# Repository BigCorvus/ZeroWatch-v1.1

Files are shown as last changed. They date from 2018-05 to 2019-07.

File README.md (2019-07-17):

# ZeroWatch-v1.1


**Replacement board for a cheap chinese U8/U80 watch.**  
Based on the work of Dan Geiger.
Features:<br />
- ATSAMD21 microcontroller with Arduino support via USB bootloader<br />
- capacitive touchscreen (based on the BL6280 controller)<br />
- HM11 bluetooth 4.0 module with amputated PCB antenna and primitive coax dipole instead<br />
- ST7735 128x128 18-pin SPI tft (the one that's inside the watch already)<br />
- MPU9250 9-DOF IMU<br />
- BME680 environmental sensor<br />
- vibration motor. I decided to go with https://de.aliexpress.com/item/Free-shipping-100pcs-lot-4-10-MM-Ultra-Micro-Vibration-Motor-Rotor-motor-DC-Massager-motor/32748925343.html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 as the vibration motor to save space for a bigger battery.<br />
- infrared transmitter (APA3010F3C-GX LED)<br />
- piezo disc (optional)<br />
- I equipped mine with a QI inductive charging pad<br />

The software is based on Dan Geigers ingenious menu structure which enables you to add new apps easily.
It's quite raw and buggy but demonstrates most features and is optimized for power consumption. With the 403030 lipo I can get 8 days of standby time with bluetooth constantly advertising and the ATSAMD21's inbuilt RTC running.<br />

**Some tips if you want to repeat the project:**  
- The cheapest versions of the U8 (there are even ones below 10$, a great contribution to a healthy environment!) are usually so stripped-down that they are not useful anymore! They have their capacitive touch controller on the main PCB an not on a flex-rigid assembly. I found the U80 by NAIKU to be a good hacking victim. Search this on Aliexpress. Its design is slightly different to the U8 from the outside but from the inside everything fits. Note: the U8 by the same brand is useless.  
  
The pic shows some useless variants on the right and some hackable ones on the left (with their 6pin FPC connectors desoldered for the most part). As you can see,on the useless variants there's no touch controller on the ribbon cable but a 15pin FPC connector with nothing but the traces to the glass. Also, v1.0 and v1.2's bare PCB are depicted on the very left ;)  

- Finding a proper screen might be a problem. 18 pin versions of the 1.44'' ST7735/ILI9163 screen with the right dimensions are rare. In fact I've only found one source: https://de.aliexpress.com/item/Maithoga-1-44-zoll-18-PIN-SPI-TFT-LCD-St7735-Stick-IC-128RGB-128/32843155779.html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. Some screens found in the cheap U8/U80 watches have weird controller settings and dispay inverted colors or don't show the small fonts so be aware. You might need to buy several differen variants. Note: only 14 of the 18 pins have to be soldered to the PCB.  
- some modifications on the enclosure are needed. In order to accommodate the v1.1 board you have to cut away the plastic brackets that surround the microphone. This is best done usind electronics side cutters. Some other plastic tabs might need to be removed depending on the variant you have. But the enclosures are surprisingly similar with few variations between versions.  
- The button can be installed either using the native one or by installing a SW1256CT-ND switch (digikey). The latter requires some hacking to the enclosure  
- a small hole has to be drilled for the IR LED if you wish to use one.
- the HM-11 should be flashed with the newest firmware before installing on the v1.1 PCB.   
- if you have a PCB manufactured, the substrate thickness should be between 0.4 and 0.8mm, so OSH Park's 0.8mm service is a good choice.
- in the latest modification I replaced the HM11 with a tiny nRF52832 module (https://de.aliexpress.com/item/32840369737.html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) which I  flashed with a modified BLE UART example inside the Adafruit nRF52 core. It can be brought into sub-µA deep sleep by the ATSAMD. By using a passthrough sketch for the ATSAMD which lets it act as an USB-to UART bridge you can even program the nRF52832 via USB and the Arduino IDE. I tested the concept and it seems to be the best solution so far. Code and wiring scheme for this will be puplished as soon as I have time for it.

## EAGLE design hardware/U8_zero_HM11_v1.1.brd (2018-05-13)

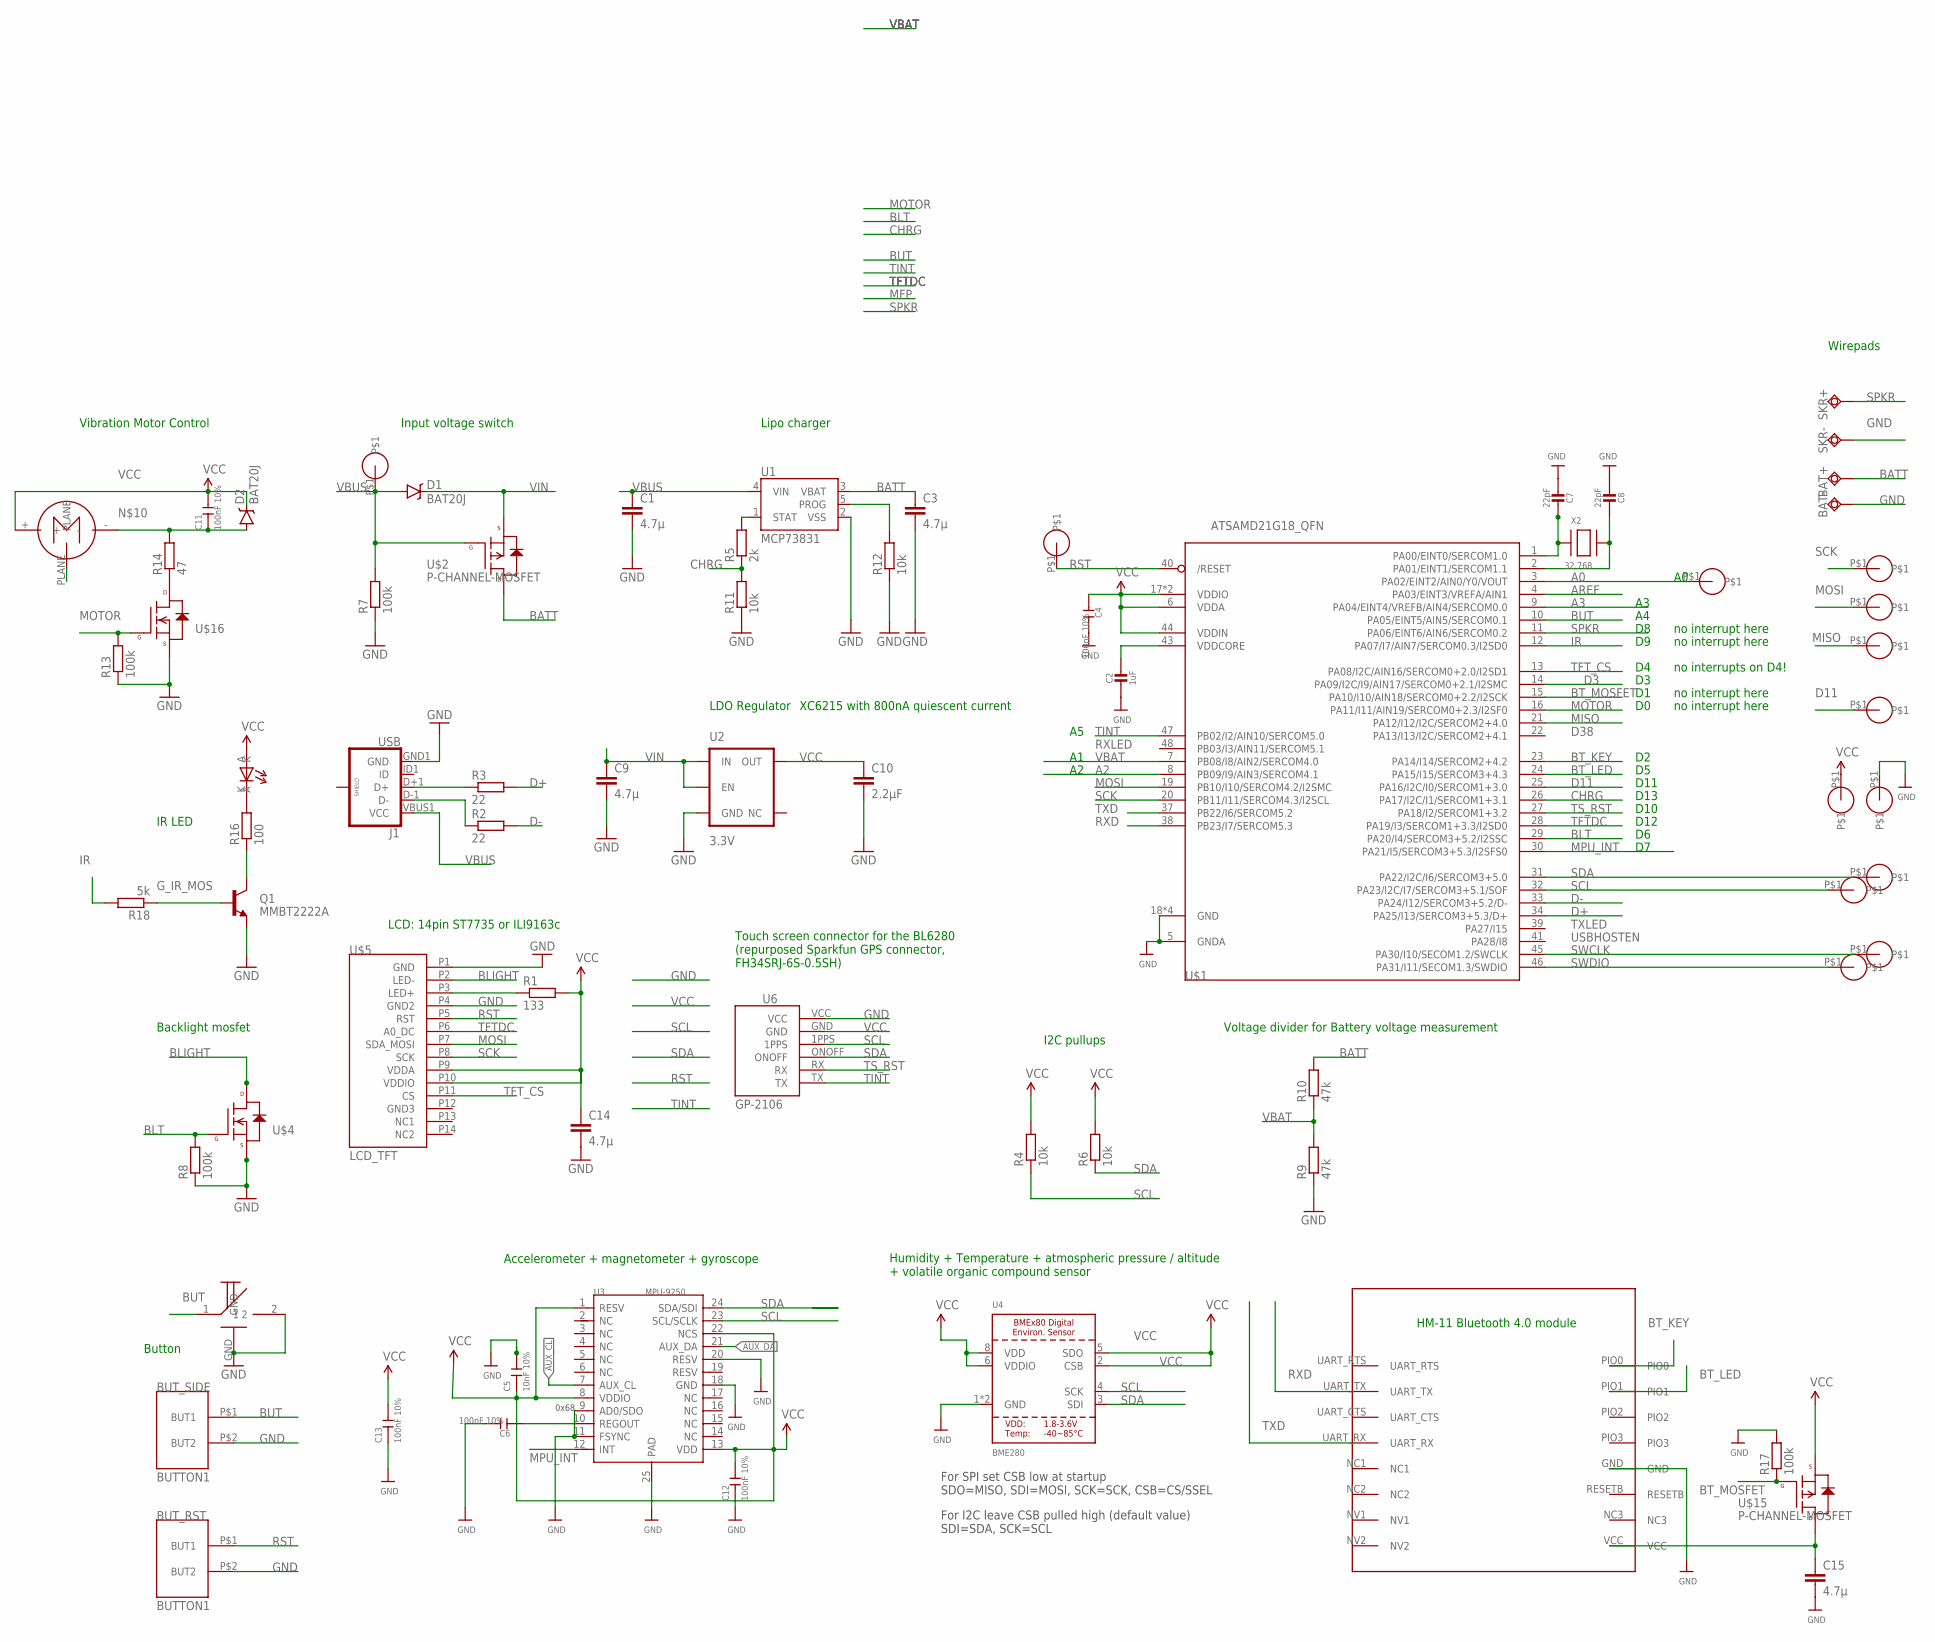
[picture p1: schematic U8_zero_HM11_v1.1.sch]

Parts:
BAT+: TPSQTP16R; TP16R
BAT-: TPSQTP16R; TP16R
BUT_RST: BUTTON1
BUT_SIDE: BUTTON1
C1, C3, C9, C14, C15: 4.7µ; C0603
C2: 1uF; 0603-NO
C4, C6, C11, C12, C13: 100nF 10%; C0603
C5: 10nF 10%; C0603
C7, C8: 22pF; 0603-NO
C10: 2.2µF; C0603
CLK: MINIPAD
D1, D2: BAT20J; SOD-323
DIO, DIO1, DIO2, DIO3, DIO4, DIO5: MINIPAD
J1: USB; USB-B-MICRO-SMD_V03
Q1: MMBT2222A; SOT23-3
R1: 133; R0603
R2, R3: 22; R0603
R4, R6, R11, R12: 10k; R0603
R5: 2k; R0603
R7, R8, R13, R17: 100k; R0603
R9, R10: 47k; R0603
R14: 47; R0603
R16: 100; R0603
R18: 5k; R0603
SKR+: TPSQTP12R; TP12R
SKR-: TPSQTP12R; TP12R
U1: MCP73831; SOT23-5
U2: 3.3V; SOT23-5
U3: MPU-9250; LEAD-QFN24
U4: BME280
U6: GP-2106
U$1: ATSAMD21G18_QFN; TQFN48_7MM
U$2, U$15: P-CHANNEL-MOSFET; SOT23-3
U$3, U$18, U$20, U$21, U$41, U$42: MINIPAD
U$4, U$16: N-CHANNEL-MOSFET-BSS138; SOT23-3
U$5: LCD_TFT; LCD_FPC14
U$8: HM-11
U$22: B3U-3100P-B
U$23: VIBRO
U$24: APA3010F3C-GX
X2: 32.768; XTAL3215

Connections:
A0: U$1.3 (PA02/EINT2/AIN0/Y0/VOUT), U$20.P$1
A2: U$1.8 (PB09/I9/AIN3/SERCOM4.1)
A3: U$1.9 (PA04/EINT4/VREFB/AIN4/SERCOM0.0)
AREF: U$1.4 (PA03/EINT3/VREFA/AIN1)
AUX_CL: U3.7 (AUX_CL)
AUX_DA: U3.21 (AUX_DA)
BATT: BAT+.TP, C3.1, R10.2, U1.3 (VBAT), U$2.3 (D)
BLIGHT: U$4.3 (D), U$5.P2 (LED-)
BLT: R8.2, U$1.29 (PA20/I4/SERCOM3+5.2/I2SSC), U$4.1 (G)
BT_KEY: U$1.23 (PA14/I14/SERCOM2+4.2), U$8.PIO0
BT_LED: U$1.24 (PA15/I15/SERCOM3+4.3), U$8.PIO1
BT_MOSFET: R17.1, U$1.15 (PA10/I10/AIN18/SERCOM0+2.2/I2SCK), U$15.1 (G)
BUT: BUT_SIDE.P$1 (BUT1), U$1.10 (PA05/EINT5/AIN5/SERCOM0.1), U$22.1
CHRG: R5.1, R11.2, U$1.26 (PA17/I2C/I1/SERCOM1+3.1)
D3: U$1.14 (PA09/I2C/I9/AIN17/SERCOM0+2.1/I2SMC)
D11: DIO4.P$1, U$1.25 (PA16/I2C/I0/SERCOM1+3.0)
D+: R3.2, U$1.34 (PA25/I13/SERCOM3+5.3/D+)
D-: R2.2, U$1.33 (PA24/I12/SERCOM3+5.2/D-)
GND: BAT-.TP, BUT_RST.P$2 (BUT2), BUT_SIDE.P$2 (BUT2), C1.2, C2.2, C3.2, C4.2, C5.2, C6.2, C7.2, C8.2, C9.2, C10.2, C12.1, C13.1, C14.2, C15.2, J1.GND1 (GND), Q1.2 (E), R7.1, R8.1, R9.1, R11.1, R12.1, R13.1, R17.2, SKR-.TP, U1.2 (VSS), U2.2 (GND), U3.9 (AD0/SDO), U3.11 (FSYNC), U3.18 (GND), U3.20 (RESV), U3.25 (PAD), U4.1 (GND), U4.7 (GND), U6.VCC, U$1.5 (GNDA), U$1.18 (GND), U$1.35 (GND), U$1.42 (GND), U$1.THERMAL (GND), U$4.2 (S), U$5.P1 (GND), U$5.P4 (GND2), U$8.GND, U$16.2 (S), U$22.2, U$22.GND, U$42.P$1
G_IR_MOS: Q1.1 (B), R18.1
IR: R18.2, U$1.12 (PA07/I7/AIN7/SERCOM0.3/I2SD0)
MISO: DIO1.P$1, U$1.21 (PA12/I12/I2C/SERCOM2+4.0)
MOSI: DIO2.P$1, U$1.19 (PB10/I10/SERCOM4.2/I2SMC), U$5.P7 (SDA_MOSI)
MOTOR: R13.2, U$1.16 (PA11/I11/AIN19/SERCOM0+2.3/I2SF0), U$16.1 (G)
MPU_INT: U3.12 (INT), U$1.30 (PA21/I5/SERCOM3+5.3/I2SFS0)
unnamed: C6.1, U3.10 (REGOUT)
unnamed: C7.1, U$1.1 (PA00/EINT0/SERCOM1.0), X2.P$1
unnamed: C8.1, U$1.2 (PA01/EINT1/SERCOM1.1), X2.P$2
unnamed: R14.1, U$16.3 (D)
unnamed: J1.D+1 (D+), R3.1
unnamed: J1.D-1 (D-), R2.1
unnamed: R12.2, U1.5 (PROG)
unnamed: R5.2, U1.1 (STAT)
unnamed: R1.1, U$5.P3 (LED+)
unnamed: C11.1, D2.A, R14.2, U$23.-
unnamed: Q1.3 (C), R16.1
unnamed: R16.2, U$24.K
unnamed: C15.1, U$8.VCC, U$15.3 (D)
PLANE: U$23.PLANE
RST: BUT_RST.P$1 (BUT1), U$1.40 (/RESET), U$3.P$1, U$5.P5 (RST)
RXD: U$1.38 (PB23/I7/SERCOM5.3), U$8.UART_TX
SCK: DIO3.P$1, U$1.20 (PB11/I11/SERCOM4.3/I2SCL), U$5.P8 (SCK)
SCL: R4.1, U3.23 (SCL/SCLK), U4.4 (SCK), U6.1PPS, U$1.32 (PA23/I2C/I7/SERCOM3+5.1/SOF), U$21.P$1
SDA: R6.1, U3.24 (SDA/SDI), U4.3 (SDI), U6.ONOFF, U$1.31 (PA22/I2C/I6/SERCOM3+5.0), U$18.P$1
SPKR: SKR+.TP, U$1.11 (PA06/EINT6/AIN6/SERCOM0.2)
SWCLK: CLK.P$1, U$1.45 (PA30/I10/SECOM1.2/SWCLK)
SWDIO: DIO.P$1, U$1.46 (PA31/I11/SECOM1.3/SWDIO)
TFTDC: U$1.28 (PA19/I3/SERCOM1+3.3/I2SD0), U$5.P6 (A0_DC)
TFT_CS: U$1.13 (PA08/I2C/AIN16/SERCOM0+2.0/I2SD1), U$5.P11 (CS)
TINT: U6.TX, U$1.47 (PB02/I2/AIN10/SERCOM5.0)
TS_RST: U6.RX, U$1.27 (PA18/I2/SERCOM1+3.2)
TXD: U$1.37 (PB22/I6/SERCOM5.2), U$8.UART_RX
VBAT: R9.2, R10.1, U$1.7 (PB08/I8/AIN2/SERCOM4.0)
VBUS: C1.1, D1.A, DIO5.P$1, J1.VBUS1 (VCC), R7.2, U1.4 (VIN), U$2.1 (G)
VCC: C4.1, C5.1, C10.1, C11.2, C12.2, C13.2, C14.1, D2.C, R1.2, R4.2, R6.2, U2.5 (OUT), U3.1 (RESV), U3.8 (VDDIO), U3.13 (VDD), U3.22 (NCS), U4.2 (CSB), U4.5 (SDO), U4.6 (VDDIO), U4.8 (VDD), U6.GND, U$1.6 (VDDA), U$1.17 (VDDIO), U$1.36 (VDDIO), U$1.44 (VDDIN), U$5.P9 (VDDA), U$5.P10 (VDDIO), U$15.2 (S), U$23.+, U$24.A, U$41.P$1
VDDCORE1: C2.1, U$1.43 (VDDCORE)
VIN: C9.1, D1.C, U2.1 (IN), U2.3 (EN), U$2.2 (S)

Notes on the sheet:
D38
TXLED
USBHOSTEN
RXLED
TXD
RXD
0x68
D12
D10
For SPI set CSB low at startup SDO=MISO, SDI=MOSI, SCK=SCK, CSB=CS/SSEL
For I2C leave CSB pulled high (default value) SDI=SDA, SCK=SCL
D11
D13
no interrupts on D4!
HM-11 Bluetooth 4.0 module
no interrupt here
LCD: 14pin ST7735 or ILI9163c
Touch screen connector for the BL6280 (repurposed Sparkfun GPS connector, FH34SRJ-6S-0.5SH)
Vibration Motor Control
Input voltage switch
Lipo charger
LDO Regulator
IR LED
Voltage divider for Battery voltage measurement
I2C pullups
Backlight mosfet
Button
Accelerometer + magnetometer + gyroscope
Humidity + Temperature + atmospheric pressure / altitude + volatile organic compound sensor
Wirepads
XC6215 with 800nA quiescent current

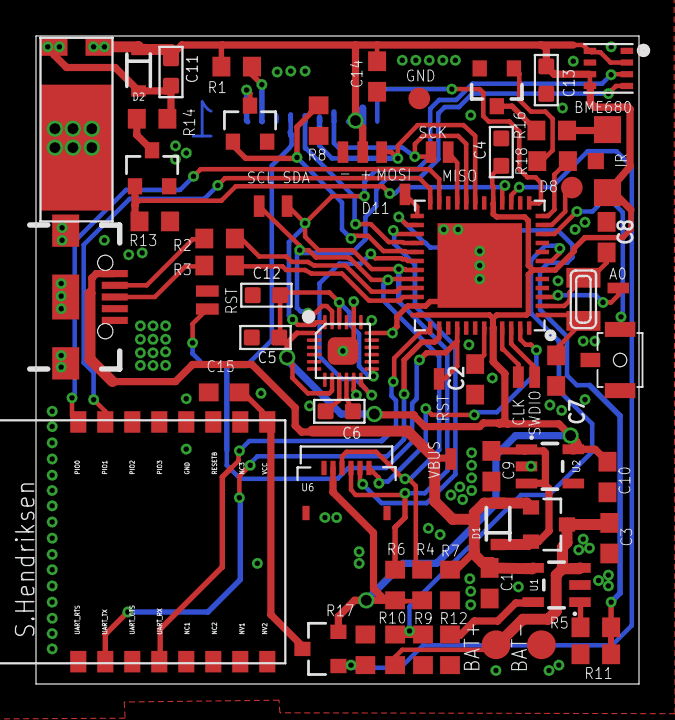
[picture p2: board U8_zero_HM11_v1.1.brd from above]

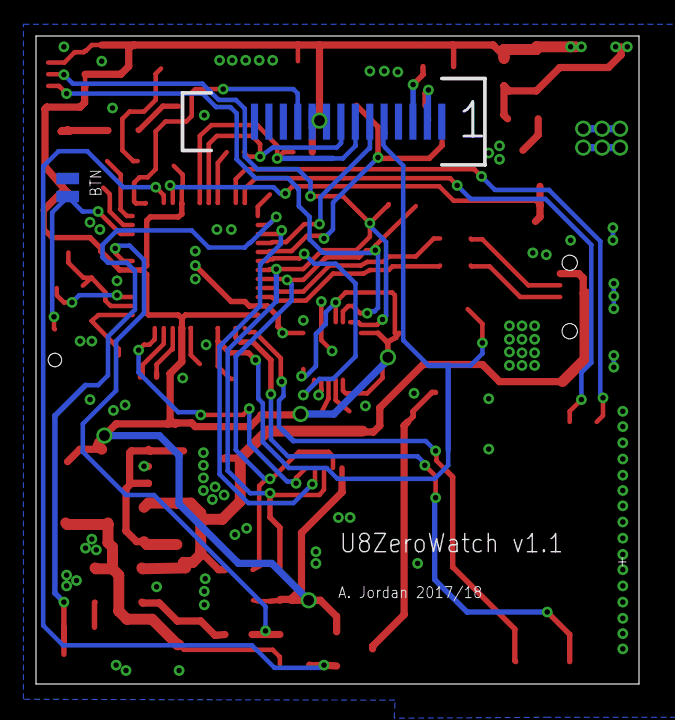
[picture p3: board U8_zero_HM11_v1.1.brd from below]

Board: 2 copper layers, 33.5 x 36.0 mm, 71 parts (2 on the bottom side), 50 nets.

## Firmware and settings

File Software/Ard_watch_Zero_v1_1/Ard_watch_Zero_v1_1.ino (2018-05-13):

#include "wiring_private.h" // pinPeripheral() function
#include <Wire.h>
#include <SPI.h>
#include <Adafruit_GFX.h>    // Core graphics library
#include <Adafruit_ST7735.h> // Hardware-specific library
#include <BL6280.h>
#include <SparkFunMPU9250-DMP.h>
#include <RTCZero.h>
#include <Adafruit_Sensor.h>
#include "Adafruit_BME680.h"
//#include "ClosedCube_BME680.h"
#include <IRLibSendBase.h>    // First include the send base
//Now include only the protocols you wish to actually use.
//The lowest numbered protocol should be first but remainder 
//can be any order.
#include <IRLib_P01_NEC.h>    
#include <IRLib_P02_Sony.h>   
#include <IRLibCombo.h>     // After all protocols, include this
// All of the above automatically creates a universal sending
// class called "IRsend" containing only the protocols you want.
// Now declare an instance of that sender.
#define SEALEVELPRESSURE_HPA (1013.25)


/* Create an rtc object */
RTCZero rtc;
/* Change these values to set the current initial time */
byte seconds = 0;
byte minutes = 00;
byte hours = 00;

/* Change these values to set the current initial date */
byte Day = 24;
byte Month = 5;
byte Year = 18;

// Color definitions
#define	BLACK   0x0000
#define	BLUE    0x001F
#define	RED     0xF800
#define	GREEN   0x07E0
#define CYAN    0x07FF
#define MAGENTA 0xF81F
#define YELLOW  0xFFE0
#define WHITE   0xFFFF

#define CS 4
#define DC 12
#define BACKLIGHT 6
#define CHARGE 13
#define BUTTON A4 //A4 is  7
#define TINT A5
#define SPKR 8
#define IR 9
#define AINT 7  //MPUinterrupt
#define VBAT A1
#define MOTOR PORT_PA11
#define TS_RST 10
#define BT_CTRL 2 //formerly SD_CS
#define BT_LED 5
#define BT_MOSFET 1


unsigned long stepCount = 0;
unsigned long stepTime = 0;
unsigned long lastStepCount = 0;

//create a new SPI for SD card
//SPIClass SD_SPI (&sercom2, 3, 5, 4, SPI_PAD_0_SCK_3, SERCOM_RX_PAD_1);
//create a new I2C for sensors
//TwoWire Sens_Wire(&sercom1, 11, 13);

const uint8_t maxApp =7;
char* const appName[] = {"Clock", "Remote", "Status", "Set T", "Bright", "Test S", "Tremor", "Compass"};
MPU9250_DMP imu;
//TFT_ILI9163C tft = TFT_ILI9163C(CS, DC);
Adafruit_ST7735 tft = Adafruit_ST7735(CS,  DC, -1);
BL6280 ctp = BL6280();
Adafruit_BME680 bme; // I2C
IRsend mySender;
//ClosedCube_BME680 bme680;

volatile boolean selButton; // the Select (side) button
volatile boolean Touched;
volatile uint8_t valBright = 100;
volatile int maxX, maxY, maxZ, minX, minY, minZ;

void setup(void) {
  delay(6000); //time to program the atsamd21 before it enters sleep mode

  Wire.begin();
  Serial.begin(9600); //serial port for communication with the BT module
  pinMode(BACKLIGHT, OUTPUT);
  digitalWrite(BACKLIGHT, LOW);
  //pinMode(MOTOR, OUTPUT);
 //digitalWrite(MOTOR, LOW);
 REG_PORT_DIRSET0 = PORT_PA11 ; // Direction set to OUTPUT
 //digitalWrite(MOTOR, LOW);
   REG_PORT_OUTCLR0 = PORT_PA11 ; // set state of pin(s) to LOW
  pinMode(BT_MOSFET, OUTPUT);
  digitalWrite(BT_MOSFET, LOW);
   pinMode(TS_RST, OUTPUT);
  digitalWrite(TS_RST, HIGH);
  pinMode(CHARGE, INPUT);
  pinMode(TINT, INPUT);
  pinMode(SPKR, OUTPUT);
  pinMode(BT_CTRL, OUTPUT);
  digitalWrite(BT_CTRL, HIGH);
  digitalWrite(SPKR, LOW);
  pinMode(AINT, INPUT_PULLUP);
pinMode(BUTTON, INPUT_PULLUP);
  attachInterrupt(BUTTON, btn_isr, LOW);//LOW is needed here in order to be able to wake the atsamd21 from deep sleep!!!!!!!!
  //attachInterrupt(AINT, mpu_isr, LOW);
 //attachInterrupt(TINT, touch_isr, CHANGE);//attachInterrupt(EXTERNAL_INT_6, ISR, FALLING);
  // Configure the regulator to run in normal mode when in standby mode
  // Otherwise it defaults to low power mode and can only supply 50 uA
  //SYSCTRL->VREG.bit.RUNSTDBY = 1;

  // Enable the DFLL48M clock in standby mode
  //SYSCTRL->DFLLCTRL.bit.RUNSTDBY = 1;
  // Set the EIC (External Interrupt Controller) to wake up the MCU
  // on an external interrupt from digital pin 0. (It's EIC channel 11)
  //EIC->WAKEUP.reg = EIC_WAKEUP_WAKEUPEN5;
  
  // Disable the USB device, this avoids USB interrupts
  // mainly the SOF every 1ms.
  // Note: you'll have to double tap the reset button to load new sketches
  //USBDevice.detach();
  rtc.begin(); //Start RTC library, this is where the clock source is initialized
  // Set the time
  rtc.setHours(hours);
  rtc.setMinutes(minutes);
  rtc.setSeconds(seconds);
  // Set the date
  rtc.setDay(Day);
  rtc.setMonth(Month);
  rtc.setYear(Year);
  rtc.setAlarmTime(00, 00, 10); //set alarm time to go off in 10 seconds
  //rtc.enableAlarm(rtc.MATCH_HHMMSS); //set alarm
  // rtc.attachInterrupt(ding); //creates an interrupt that wakes the SAMD21 which is triggered by a FTC alarm 
  tft.initR(INITR_GREENTAB);
  tft.setRotation(0);
  tft.setTextColor(WHITE, BLACK);
  backLight(0);
  selButton = false;
  Touched = false;
  BTwake();
  BTsetup();
 
//basicIMUsetup();
   
//basicBMEsetup();  
 
  
   ctp.begin();
   

  tone(SPKR, 1000, 200);
vibrate();


  //rtc.setAlarmTime(00, 00, 10); //set alarm time to go off in 10 seconds

  //following two lines enable alarm, comment both out if you want to do external interrupt
  // rtc.enableAlarm(rtc.MATCH_HHMMSS); //set alarm
  //rtc.attachInterrupt(ding); //creates an interrupt that wakes the SAMD21 which is triggered by a FTC alarm
  // attachInterrupt(BUTTON, ISR, LOW);
  //comment out the below line if you are using RTC alarm for interrupt
  //extInterrupt(A1); //creates an interrupt source on external pin
}

void loop() {

  modeSleep(); // Shutdown systems for sleep
  //  sleep_mode(); // go to sleep
 // rtc.standbyMode(); //library call
  samSleep();
  modeWake();

  delay(300); //debounce
  selButton = false;
  backLight(valBright);
  appClock();
  unsigned long timer1 = millis() + 5000; //Display stays on 5 seconds
  uint8_t sApp = 0;

  while (millis() < timer1) {
    if ( selButton == true) {
      tone(SPKR, 2000, 70);
      delay(100); //debounce
      selButton = false;
    }
    //Look for the gesture
    if (ctp.touched()) {
      //Touched = false;
      sApp = appMenu();
      //appName[] = {"Clock", "Remote", "Status", "Set T", "Bright", "Test S", "Tremor", "Compass"};
      switch (sApp) {
        case 0:
          timer1 = millis() + 5000;
          appClock();
          break;
        case 1:
          appRemote();
          break;
        case 2:
          appStatus();
          break;
        case 3:
          appSetTime();
          break;
        case 4:
          appSetBright();
          break;
        case 5:
          appTestS();
          break;
        case 6:
          appTremor();
          break;
        case 7:
          appCompass();
          break;
      }
    }
    if(digitalRead(TINT)==LOW){
      //tone(SPKR,1000,20);
    }
  }

  tft.fillScreen(BLACK);
  backLight(0);
  delay(5);

}

void btn_isr()
{
  selButton = true;
  //backLight(0);
  
}

void touch_isr()
{
  //tone(SPKR,1000,20);
  //if(ctp.touched())
  //Touched = true;
  //selButton = true;
  //backLight(0);
}

void mpu_isr()
{
   
}

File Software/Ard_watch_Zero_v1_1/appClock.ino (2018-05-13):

//----------------------------
// Draw the default clock face
//----------------------------

void appClock(void) {
 // time_t t ;//RTC.get();

  tft.fillScreen(BLACK);
  tft.setCursor(10, 10);
  tft.setTextColor(BLUE);
  tft.setTextSize(2);
  tft.println("Time");

  // Print Time
  tft.setCursor(10, 40);
  tft.setTextSize(3);
  tft.setTextColor(GREEN);
  if (rtc.getHours() < 10) tft.print(" ");
  tft.print(rtc.getHours());
  tft.print(":");
  if (rtc.getMinutes() < 10) tft.print("0");
  tft.print(rtc.getMinutes());

  // Print Date
  tft.setTextColor(GREEN);
  tft.setTextSize(1);
  tft.setCursor(30, 90);
  tft.print(rtc.getDay());
  tft.print(".");
  tft.print(rtc.getMonth());
  tft.print(".");
  tft.print(rtc.getYear());


  // Voltage
  tft.setCursor(10, 110);

  if (USBDevice.connected()) {
    if (digitalRead(CHARGE)) {
      tft.setTextColor(CYAN);
      tft.print("Charged");
    }
    else {
      tft.setTextColor(RED);
      tft.print("Charging...");
    }
  } 
  tft.setCursor(10, 120);
  tft.setTextColor(CYAN);
   // power_adc_enable();
    tft.print(analogRead(VBAT)*.0064886, 2);
    tft.print(" V  ");
   // power_adc_disable();
  

}
/*
time_t compileTime(void)
{
  char *compDate = __DATE__, *compTime = __TIME__, *months = "JanFebMarAprMayJunJulAugSepOctNovDec";
  char chMon[3], *m;
  int d, y;
  tmElements_t tm;
  time_t t;

  strncpy(chMon, compDate, 3);
  chMon[3] = '\0';
  m = strstr(months, chMon);
  tm.Month = ((m - months) / 3 + 1);

  tm.Day = atoi(compDate + 4);
  tm.Year = atoi(compDate + 7) - 1970;
  tm.Hour = atoi(compTime);
  tm.Minute = atoi(compTime + 3);
  tm.Second = atoi(compTime + 6);
  t = makeTime(tm);
  return t + 10;        //add fudge factor to allow for compile time
}
*/

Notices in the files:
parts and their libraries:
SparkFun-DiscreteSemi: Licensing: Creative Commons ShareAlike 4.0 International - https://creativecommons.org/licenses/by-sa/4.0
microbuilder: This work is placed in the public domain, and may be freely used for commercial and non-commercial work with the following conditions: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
